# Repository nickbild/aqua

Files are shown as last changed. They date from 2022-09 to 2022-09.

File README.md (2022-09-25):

# Aqua

Aqua turns the underpowered Mattel Aquarius into a respectable computer by adding 32 KB of RAM and SD card mass storage.

The Mattel Aquarius home computer was released in June of 1983 and had already been discontinued by October of that same year.  The short lifespan of this machine is no big surprise — it is equipped with 4 KB of RAM, which is reduced to 1.7 KB of free RAM after factoring in the reserved video memory and system variables.  It also has a terrible rubber chiclet keyboard that is not quite large enough for adult hands.  But despite these (and many more!) flaws, beyond all reason, I still love this computer so I wanted to give mine a little help.  By adding 32 KB of additional memory it is much more usable, and the SD card reader allows me to write software on a modern machine, then easily load it onto the Aquarius, which means I don't have to try to type in long programs on its awful keyboard (or use the cassette port, which is slow and fails far more than it succeeds).

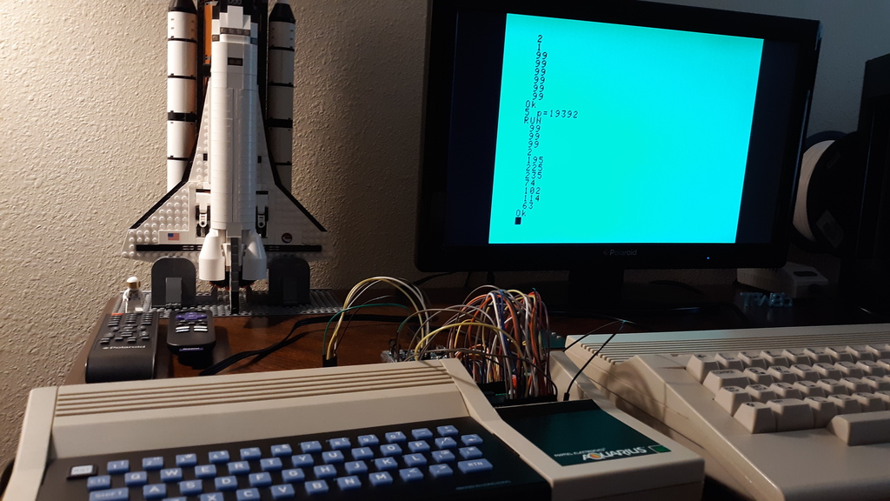
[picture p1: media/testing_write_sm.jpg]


## How It Works

The Aqua PCB ([KiCad files here](https://github.com/nickbild/aqua/tree/main/aqua_pcb)) is designed to plug into the cartridge port of the Aquarius.  It has a 32 KB SRAM chip and logic chips to map it into the 32K addresses above onboard memory ($4000-$BFFF).  It also has a pin header that gives easy access to the cartridge port's connectors.  These are quite useful since the computer offers hardly any other options for extension, and the cartridge port offers direct, unbuffered access to the address and data bus, and virtually all other signals on the Z80.

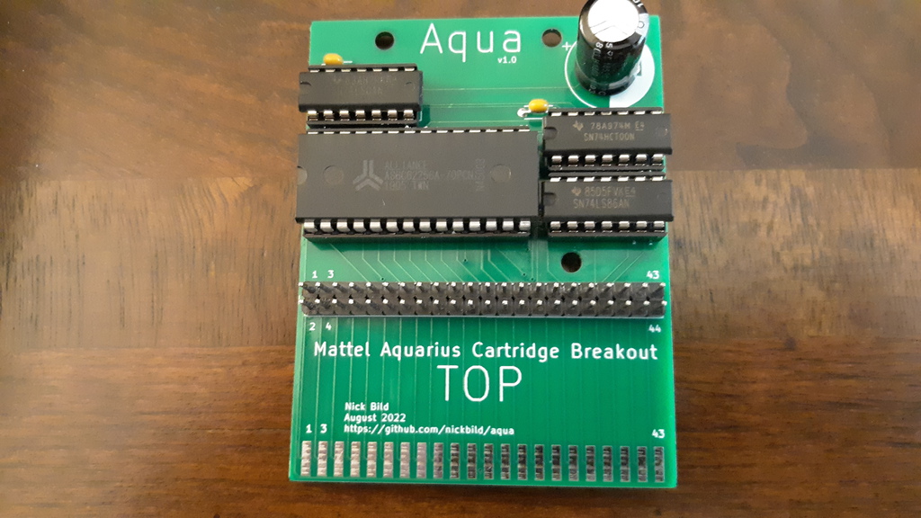
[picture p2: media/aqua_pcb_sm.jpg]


Aqua brings the Aquarius closer to being in the same league as other contemporary computers, but there is still no decent way to load programs onto it — and using the computer's keyboard to type them is a terrible experience.  So I built AquaWrite, which connects to Aqua's pin header, to load programs/data into memory on the Aquarius from an SD card.  Using AquaWrite, it is possible to write and assemble programs on a modern computer, then write the machine code, as a sequence of newline-delimited bytes, to a text file.  That card can be inserted into AquaWrite and loaded into memory in a few seconds.

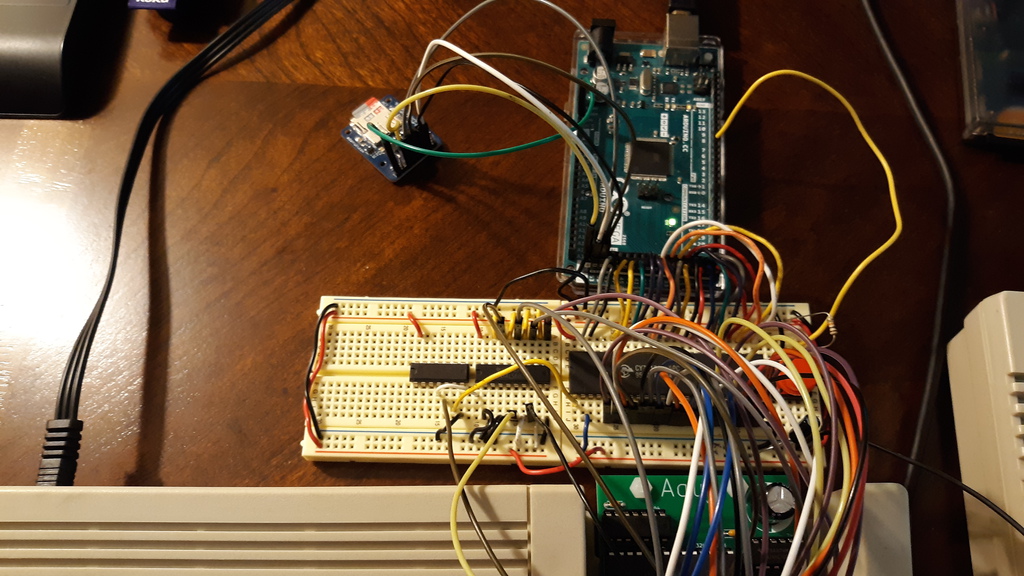
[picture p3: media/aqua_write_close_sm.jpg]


AquaWrite ([KiCad files here](https://github.com/nickbild/aqua/tree/main/aqua_write_pcb)) uses an Arduino Mega 2560 ([Arduino code here](https://github.com/nickbild/aqua/tree/main/aqua_write)) to handle SD card access and writing that data to a 1 KB dual-port SRAM chip.  That SRAM chip is mapped to addresses $FC00-$FFFF, and is used to transfer programs of any size into lower memory addresses in 1 KB pages.  The Arduino first writes a small (20 byte) program in machine code to the SRAM, then the next 1,004 bytes to be transferred.  When ready, the user is prompted to run a `USR` call that executes the machine code and transfers the bytes to a lower memory address.  This method is used because the Aquarius prevents access to addresses in the range of this SRAM from BASIC.  If the data to transfer exceeds 1004 bytes, the user presses a button on AquaWrite to load up each additional segment, then again runs `USR` to move the data to the next set of memory addresses.  Any size program (up to the limits of the Aquarius' memory) can be loaded in this way.

This is a bit more complicated because the Aquarius uses an early form of copy protection for external devices (anything that is not onboard the stock computer).  A PLA sits between the Z80 and data bus that XORs data with a software lock code (initialized to a random value on startup), which would scramble any values loaded via SD.  So before using AquaWrite for the first time after start up, a sequence of commands needs to run to disable this software lock:

```
poke 14510,63
poke 14412,63
poke 14530,63

10 print 1
run

poke 15250,175
poke 15251,211
poke 15252,255
poke 15253,201

poke 14341,59
poke 14340,146
x=usr(0)

poke 14510,191
poke 14412,191
poke 14530,191

run
```

This (temporarily) relocates the stack and other system variables to onboard memory (before the lock code is changed and they get scrambled), then runs a simple program that writes a `0` to the I/O port at $FF that stores the software lock code.  Since data is encoded/decoded by XORing it with the lock code, setting that code to `0` effectively turns it off — the result is always the same as the initial value.

Aqua:


AquaWrite:


## Media

The Aqua board, which adds 32 KB of SRAM and breaks the cartridge port connectors out into a pin header for easy access:

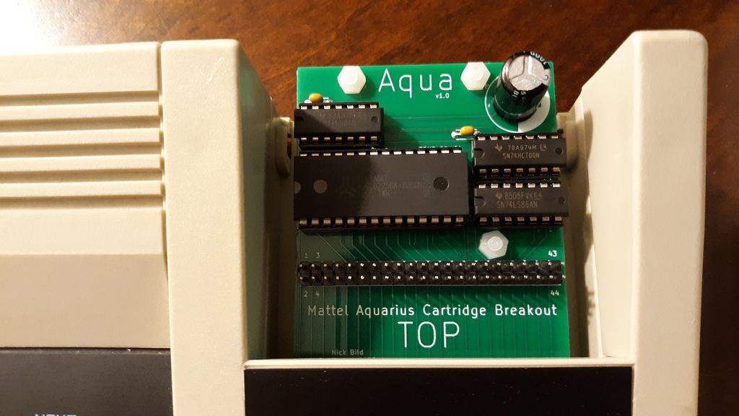
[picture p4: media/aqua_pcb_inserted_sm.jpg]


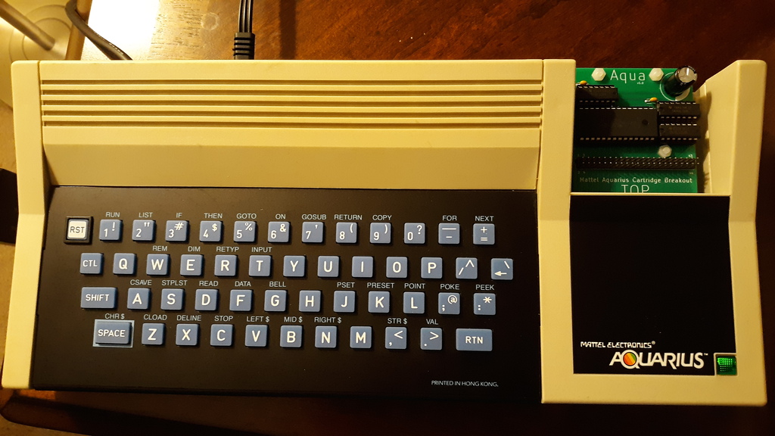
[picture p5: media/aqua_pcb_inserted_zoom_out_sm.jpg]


AquaWrite, which enables loading data from an SD card to Aquarius RAM:

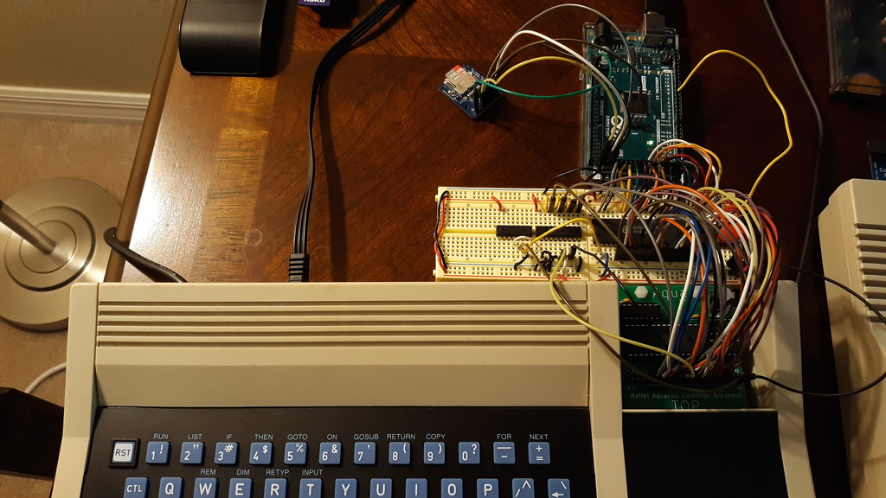
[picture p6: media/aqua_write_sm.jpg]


## Bill of Materials

Aqua:
- Aqua PCB ([KiCad files here](https://github.com/nickbild/aqua/tree/main/aqua_pcb))
- 1 x 32 KB SRAM chip
- 1 x 74LS00
- 1 x 74LS86
- 1 x 74LS04
- 4 x 0.1 uF ceramic capacitors
- 1 x 1000 uF electrolytic capacitor
- 2 x 10mm M3 standoffs
- 2 x 15mm M3 standoffs
- 44 x male pin headers

AquaWrite:
- 1 x CY7C130-55PC 1 KB dual-port SRAM
- 1 x 74LS682
- 1 x 74LS32
- 1 x Arduino Mega 2560
- 1 x SD card breakout board
- 1 x 0.1 uF ceramic capacitors
- 1 x 47 uF electrolytic capacitor
- 1 x 10K ohm resistor
- 1 x pushbutton

## About the Author

[Nick A. Bild, MS](https://nickbild79.firebaseapp.com/#!/)

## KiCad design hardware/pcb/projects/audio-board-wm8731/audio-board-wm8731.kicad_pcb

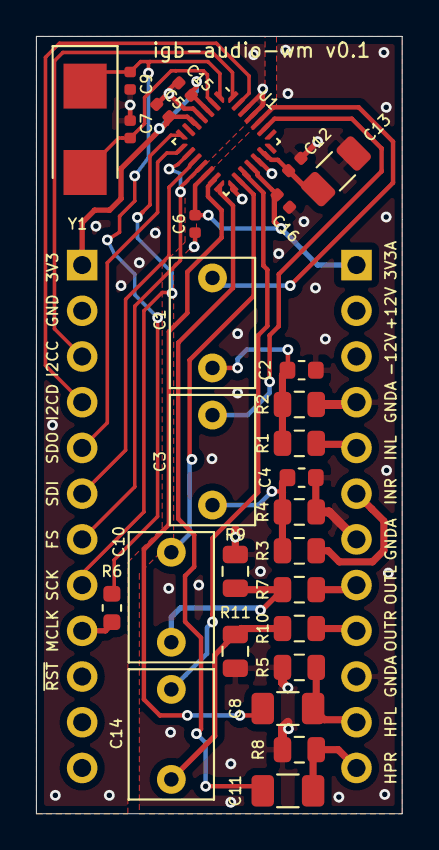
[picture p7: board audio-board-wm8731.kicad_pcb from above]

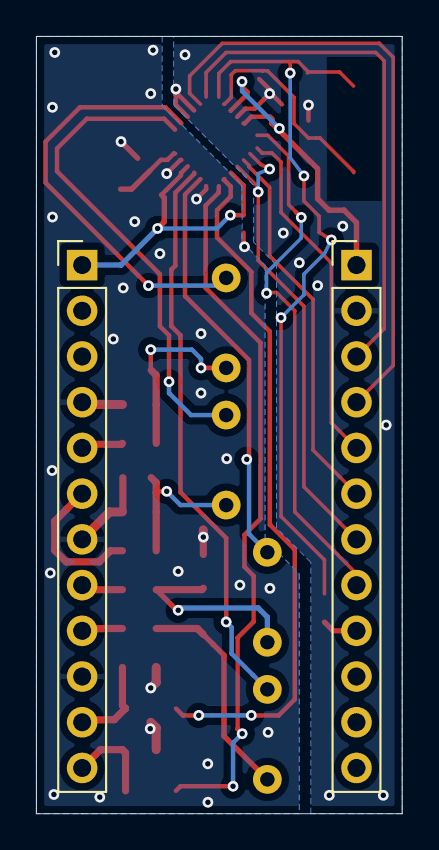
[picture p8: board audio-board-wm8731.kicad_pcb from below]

Board: 2 copper layers, 20.3 x 43.2 mm, 31 parts (2 on the bottom side), 30 nets.

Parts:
C1, C3, C10, C14: 1u; C_Rect_L7.0mm_W4.5mm_P5.00mm
C2, C4: 220p; C_0603_1608Metric
C5, C6, C12, C15, C16: 100n; C_0402_1005Metric
C7, C9: 18p; C_0402_1005Metric
C8, C11: 100u; C_1206_3216Metric
C13: 10u; C_1206_3216Metric
J1, J2: Conn_01x12; PinHeader_1x12_P2.54mm_Vertical
R1, R2, R3, R4: 10k; R_0805_2012Metric
R5, R8, R9, R11: 100k; R_0805_2012Metric
R6: 0; R_0603_1608Metric
R7, R10: 100; R_0805_2012Metric
U1: wm8731_qfn; QFN-28_4x4mm_P0.5mm
Y1: 12.288MHz; Crystal_SMD_Abracon_ABM3-2pin_5.0x3.2mm_hand

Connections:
+3.3VA: C6.2, C16.2, J1.1, U1.12, U1.18
+3V3: C5.2, C15.2, J2.1, U1.3, U1.5
/ADC_L: C1.2, U1.24
/ADC_R: C3.2, U1.23
/DAC_L: C10.2, U1.16
/DAC_R: C14.2, U1.17
/HP_OUT_L: C8.2, J1.11, R5.2
/HP_OUT_R: C11.2, J1.12, R8.2
/I2C_SCL: J2.3, U1.28
/I2C_SDA: J2.4, U1.27
/I2S_FS: J2.7, U1.9, U1.11
/I2S_MCLK: J2.9, R6.1
/I2S_SCK: J2.8, U1.7
/I2S_SDI: J2.6, U1.10
/I2S_SDO: J2.5, U1.8
/LINE_IN_L: J1.5, R1.2
/LINE_IN_R: J1.6, R3.2
/LINE_OUT_L: J1.8, R7.2
/LINE_OUT_R: J1.9, R10.2
GND: C5.1, C7.2, C9.2, C15.1, J2.2, U1.4, U1.25, U1.26
GNDA: C2.1, C4.1, C6.1, C12.2, C13.2, C16.1, J1.4, J1.7, J1.10, R2.2, R4.2, R5.1, R8.1, R9.1, R11.1, U1.15, U1.19
unnamed: C1.1, C2.2, R1.1, R2.1
unnamed: C3.1, C4.2, R3.1, R4.1
unnamed: C7.1, U1.2, Y1.2
unnamed: C8.1, U1.13
unnamed: C9.1, R6.2, U1.1, Y1.1
unnamed: C10.1, R7.1, R9.2
unnamed: C11.1, U1.14
unnamed: C12.1, C13.1, U1.20
unnamed: C14.1, R10.1, R11.2

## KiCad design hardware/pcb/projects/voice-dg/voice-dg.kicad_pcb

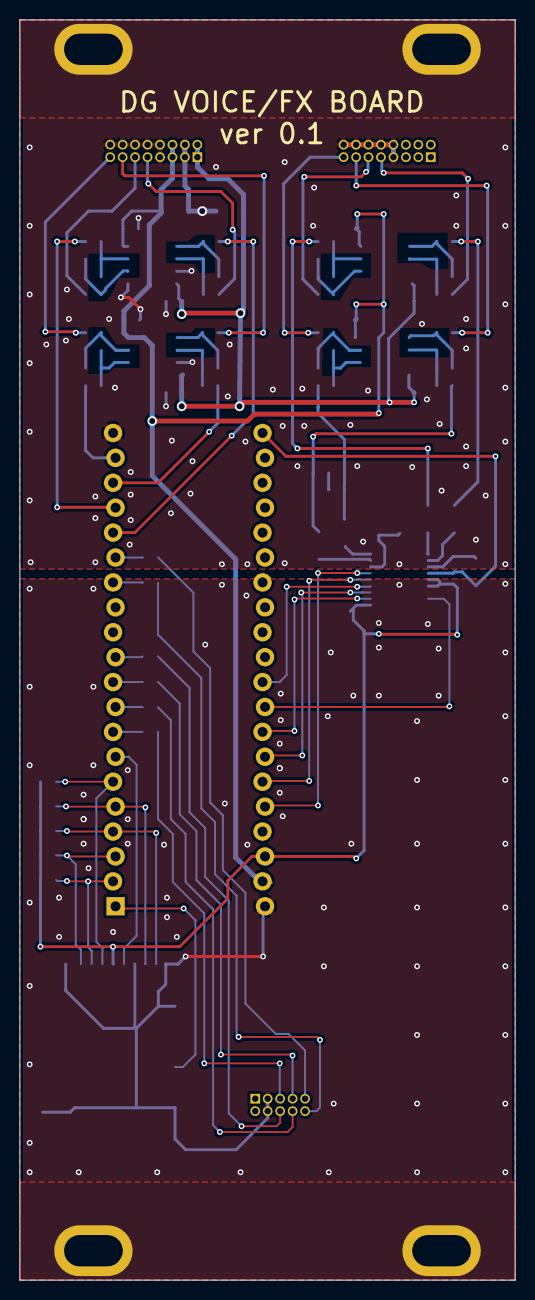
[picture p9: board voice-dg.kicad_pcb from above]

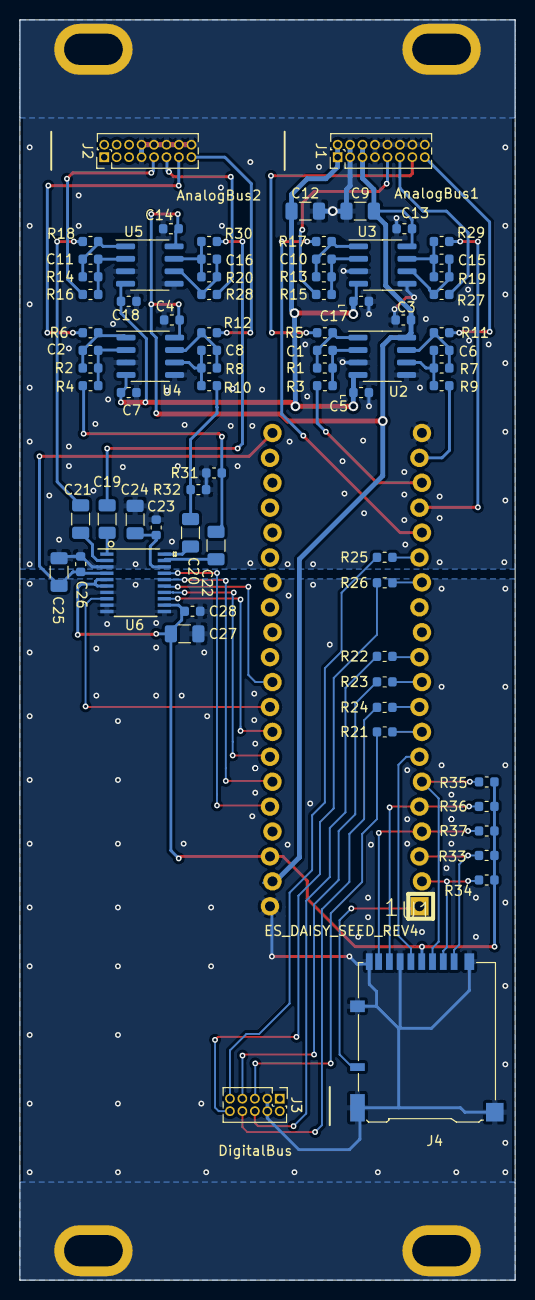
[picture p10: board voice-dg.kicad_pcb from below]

Board: 2 copper layers, 50.5 x 128.5 mm, 75 parts (75 on the bottom side), 68 nets.

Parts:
C1, C2, C6, C8, C10, C11, C15, C16: 12p; C_0603_1608Metric
C3, C4, C5, C7, C13, C14, C17, C18, C23, C26, C28: 100n; C_0603_1608Metric
C9, C12: 22u; C_1206_3216Metric
C19, C20, C21, C22, C25, C27: 10u; C_1206_3216Metric
C24: 2.2u; C_1206_3216Metric
J1: AnalogBus; PinHeader_2x08_P1.27mm_Vertical
J2: AnalogBusEx; PinHeader_2x08_P1.27mm_Vertical
J3: DigitalBus; PinHeader_2x05_P1.27mm_Vertical
J4: Micro_SD_Card_Det_Hirose_DM3AT; microSD_HC_Hirose_DM3AT-SF-PEJM5_hand
R1, R2, R7, R8, R15, R16, R27, R28: 100k; R_0603_1608Metric
R3, R4, R9, R10, R13, R14, R19, R20: 10k; R_0603_1608Metric
R5, R6, R11, R12, R17, R18, R29, R30: 470; R_0603_1608Metric
R21, R22, R23, R24, R25, R26: 47; R_0603_1608Metric
R31, R32, R33, R34, R35, R36, R37: 47k; R_0603_1608Metric
U1: ES_DAISY_SEED_REV4; ES_DAISY_SEED
U2, U3, U4, U5: OPA2134; SOIC-8_3.9x4.9mm_P1.27mm
U6: AK4556VT

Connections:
+3.3VA: C25.2, C26.1, U1.21, U6.4
+3V3: C27.2, C28.1, J4.4, R33.2, R34.2, R35.2, R36.2, R37.2, U1.38, U6.5, U6.6, U6.12
+12V: C3.1, C4.1, C9.2, C13.1, C14.1, J1.5, J1.6, U1.39, U2.8, U3.8, U4.8, U5.8
-12V: C5.1, C7.1, C12.1, C17.1, C18.1, J1.1, J1.2, U2.4, U3.4, U4.4, U5.4
/AK4556_RST: U1.36, U6.17
/AnalogIn1: J1.9, R15.2
/AnalogIn2: J1.11, R27.2
/AnalogIn3: J2.9, R16.2
/AnalogIn4: J2.11, R28.2
/AnalogOut1: J1.13, R5.1
/AnalogOut2: J1.15, R11.1
/AnalogOut3: J2.13, R6.1
/AnalogOut4: J2.15, R12.1
/DG_AUDIO_IN_L: R17.1, U1.16
/DG_AUDIO_IN_R: R29.1, U1.17
/DG_AUDIO_OUT_L: R3.2, U1.18
/DG_AUDIO_OUT_R: R9.2, U1.19
/EX_AUDIO_IN_L: C21.1, R18.1
/EX_AUDIO_IN_R: C19.1, R30.1
/EX_AUDIO_OUT_L: C22.2, R4.2, R31.2
/EX_AUDIO_OUT_R: C20.2, R10.2, R32.2
/SAI2_FS_B: U1.34, U6.14
/SAI2_MCLK_B: U1.31, U6.15
/SAI2_SCK_B: U1.35, U6.16
/SAI2_SD_A: U1.33, U6.13
/SAI2_SD_B: U1.32, U6.8
/SD_CLK: J4.5, U1.7
/SD_CMD: J4.3, R35.1, U1.6
/SD_D0: J4.7, R36.1, U1.5
/SD_D1: J4.8, R37.1, U1.4
/SD_D2: J4.1, R33.1, U1.3
/SD_D3: J4.2, R34.1, U1.2
/SPI_MISO: R23.2, U1.10
/SPI_MOSI: R22.1, U1.11
/SPI_SCK: R24.1, U1.9
/USART_RX: R25.2, U1.15
/USART_TX: R26.1, U1.14
/~SD_SW: J4.10, U1.1
/~SPI_CS: R21.2, U1.8
GND: C27.1, C28.2, J3.3, J3.4, J4.6, J4.9, J4.11, U1.40, U6.7, U6.9, U6.10, U6.11
GNDA: C3.2, C4.2, C5.2, C7.2, C9.1, C12.2, C13.2, C14.2, C17.2, C18.2, C23.2, C24.1, C25.1, C26.2, J1.3, J1.4, J1.7, J1.8, J1.10, J1.12, J1.14, J1.16, J2.7, J2.8, J2.10, J2.12, J2.14, J2.16, R31.1, R32.1, U1.20, U2.3, U2.5, U3.3, U3.5, U4.3, U4.5, U5.3, U5.5, U6.3
unnamed: C1.1, R1.1, R5.2, U2.1
unnamed: C1.2, R1.2, R3.1, U2.2
unnamed: C2.1, R2.1, R6.2, U4.1
unnamed: C2.2, R2.2, R4.1, U4.2
unnamed: C6.1, R7.1, R11.2, U2.7
unnamed: C6.2, R7.2, R9.1, U2.6
unnamed: C8.1, R8.1, R12.2, U4.7
unnamed: C8.2, R8.2, R10.1, U4.6
unnamed: C10.1, R13.1, R17.2, U3.1
unnamed: C10.2, R13.2, R15.1, U3.2
unnamed: C11.1, R14.1, R18.2, U5.1
unnamed: C11.2, R14.2, R16.1, U5.2
unnamed: C15.1, R19.1, R29.2, U3.7
unnamed: C15.2, R19.2, R27.1, U3.6
unnamed: C16.1, R20.1, R30.2, U5.7
unnamed: C16.2, R20.2, R28.1, U5.6
unnamed: C19.2, U6.1
unnamed: C20.1, U6.20
unnamed: C21.2, U6.2
unnamed: C22.1, U6.19
unnamed: C23.1, C24.2, U6.18
unnamed: J3.5, R21.1
unnamed: J3.6, R22.2
unnamed: J3.7, R23.1
unnamed: J3.8, R24.2
unnamed: J3.9, R25.1
unnamed: J3.10, R26.2

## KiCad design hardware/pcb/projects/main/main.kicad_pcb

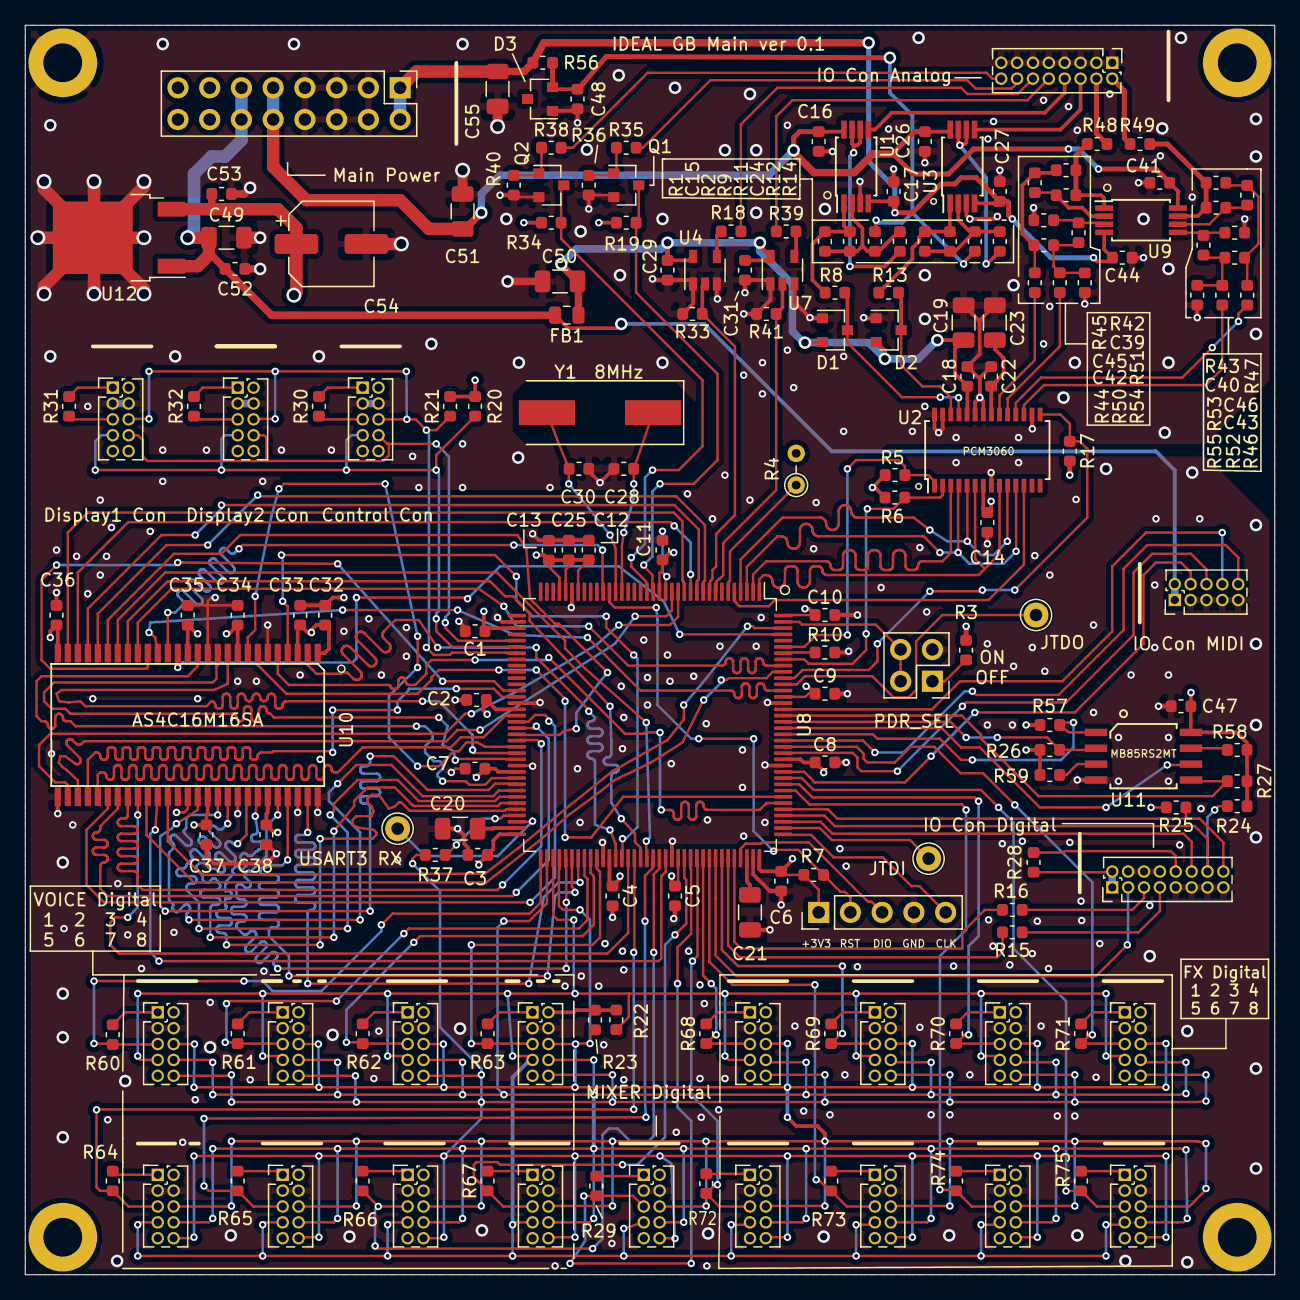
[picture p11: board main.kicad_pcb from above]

Board: 4 copper layers, 100.0 x 100.0 mm, 176 parts (0 on the bottom side), 154 nets.

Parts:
C1, C2, C3, C4, C5, C6, C7, C8, C9, C10, C11, C12, C13, C14, C16, C17, C18, C22, C25, C26, C27, C29, C31, C32, C33, C34, C35, C36, C37, C38, C41, C44, C47, C48, C52, C53: 100n; C_0603_1608Metric
C15, C24, C28, C30: 18p; C_0603_1608Metric
C19, C23: 10u; C_1206_3216Metric
C20, C21: 2.2u; C_1206_3216Metric
C39, C40, C45, C46: 470p; C_0603_1608Metric
C42, C43: 2.2n; C_0603_1608Metric
C49, C50, C51, C55: 22u; C_1206_3216Metric
C54: 100u; CP_Elec_6.3x5.3
D1, D2: BAT54S; SOT-23
D3: LM4040; SOT-23
FB1: Ferrite; R_0805_2012Metric
J1: IO_CON_ANALOG; PinHeader_2x08_P1.27mm_Vertical
J2: PDR_ON_SEL; PinHeader_2x02_P2.54mm_Vertical
J3: VOICE1_DIGITAL; PinHeader_2x05_P1.27mm_Vertical
J4: FX1_DIGITAL; PinHeader_2x05_P1.27mm_Vertical
J5: VOICE5_DIGITAL; PinHeader_2x05_P1.27mm_Vertical
J6: FX5_DIGITAL; PinHeader_2x05_P1.27mm_Vertical
J7: VOICE2_DIGITAL; PinHeader_2x05_P1.27mm_Vertical
J8: FX2_DIGITAL; PinHeader_2x05_P1.27mm_Vertical
J9: VOICE6_DIGITAL; PinHeader_2x05_P1.27mm_Vertical
J10: FX6_DIGITAL; PinHeader_2x05_P1.27mm_Vertical
J11: VOICE3_DIGITAL; PinHeader_2x05_P1.27mm_Vertical
J12: FX3_DIGITAL; PinHeader_2x05_P1.27mm_Vertical
J13: VOICE7_DIGITAL; PinHeader_2x05_P1.27mm_Vertical
J14: FX7_DIGITAL; PinHeader_2x05_P1.27mm_Vertical
J15: IO_CON_MIDI; PinHeader_2x05_P1.27mm_Vertical
J16: VOICE4_DIGITAL; PinHeader_2x05_P1.27mm_Vertical
J17: FX4_DIGITAL; PinHeader_2x05_P1.27mm_Vertical
J18: VOICE8_DIGITAL; PinHeader_2x05_P1.27mm_Vertical
J19: FX8_DIGITAL; PinHeader_2x05_P1.27mm_Vertical
J20: SWD_CON; PinHeader_1x05_P2.54mm_Vertical
J21: MIXER_DIGITAL; PinHeader_2x05_P1.27mm_Vertical
J22: DISPLAY1_DIGITAL; PinHeader_2x05_P1.27mm_Vertical
J23: IO_CON_DIGITAL; PinHeader_2x08_P1.27mm_Vertical
J24: POWER_CON; PinHeader_2x08_P2.54mm_Vertical
J25: CONTROL_DIGTAL; PinHeader_2x05_P1.27mm_Vertical
J26: DISPLAY2_DIGITAL; PinHeader_2x05_P1.27mm_Vertical
Q1, Q2: MMBT3904; SOT-23
R1, R11: 30k; R_0603_1608Metric
R2, R12: 120k; R_0603_1608Metric
R3, R5, R6, R7, R10, R17, R19, R20, R21, R22, R23, R24, R25, R26, R27, R28, R29, R30, R31, R32, R33, R34, R41, R57, R58, R59, R60, R61, R62, R63, R64, R65, R66, R67, R68, R69, R70, R71, R72, R73, R74, R75: 10k; R_0603_1608Metric
R4: 0; R_Axial_DIN0204_L3.6mm_D1.6mm_P2.54mm_Vertical
R8, R13, R48, R49: 470; R_0603_1608Metric
R9, R14: 200k; R_0603_1608Metric
R15, R16, R37: 10; R_0603_1608Metric
R18, R39, R45, R47, R51, R53: 1k; R_0603_1608Metric
R35, R36, R38, R40: 100k; R_0603_1608Metric
R42, R43, R54, R55: 12k; R_0603_1608Metric
R44, R46, R50, R52: 4.7k; R_0603_1608Metric
R56: 3.3k; R_0603_1608Metric
TP1: JTDI; Pin_D1.0mm_L10.0mm
TP2: JTDO; Pin_D1.0mm_L10.0mm
TP3: USART3_RX; Pin_D1.0mm_L10.0mm
U1, U3, U9: TL072; TSSOP-8_4.4x3mm_P0.65mm
U2: PCM3060; TSSOP-28_4.4x9.7mm_P0.65mm
U4, U7: 74AHCT1G125; SOT-23-5
U8: STM32F446ZETx; LQFP-144_20x20mm_P0.5mm
U10: AS4C16M16SA
U11: MB85RS2MT
U12: L7803; TO-252-2
Y1: 8MHz; Crystal_SMD_HC49-SD

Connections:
+3V3: C1.1, C2.1, C3.1, C4.1, C5.1, C6.1, C7.1, C8.1, C9.1, C10.1, C11.1, C12.1, C13.1, C14.1, C25.1, C32.1, C33.1, C34.1, C35.1, C36.1, C37.1, C38.1, C47.2, C53.1, C54.1, J3.1, J3.2, J4.1, J4.2, J5.1, J5.2, J6.1, J6.2, J7.1, J7.2, J8.1, J8.2, J9.1, J9.2, J10.1, J10.2, J11.1, J11.2, J12.1, J12.2, J13.1, J13.2, J14.1, J14.2, J16.1, J16.2, J17.1, J17.2, J18.1, J18.2, J19.1, J19.2, J20.1, J21.1, J21.2, J22.1, J22.2, J23.1, J23.2, J25.1, J25.2, J26.1, J26.2, R3.2, R4.2, R5.2, R6.2, R7.2, R17.2, R19.1, R20.2, R21.2, R22.2, R23.2, R24.2, R25.2, R26.2, R27.2, R28.2, R29.2, R30.2, R31.2, R32.2, R34.1, R57.2, R58.2, R59.2, R60.2, R61.2, R62.2, R63.2, R64.2, R65.2, R66.2, R67.2, R68.2, R69.2, R70.2, R71.2, R72.2, R73.2, R74.2, R75.2, U2.7, U8.17, U8.30, U8.32, U8.33, U8.39, U8.52, U8.62, U8.72, U8.84, U8.95, U8.108, U8.121, U8.131, U8.144, U10.1, U10.3, U10.9, U10.14, U10.27, U10.43, U10.49, U11.8, U12.3
+5V: C49.1, C52.1, FB1.2, J15.1, J15.2, J24.11, J24.12, U12.1
+5VA: C18.1, C19.1, C29.1, C31.1, C50.1, D1.2, D2.2, FB1.1, U2.24, U4.5, U7.5
+12V: C16.1, C26.1, C41.1, C51.1, J24.9, J24.10, U1.8, U3.8, U9.8
-12V: C17.2, C27.2, C44.2, C55.2, J24.1, J24.2, R56.2, U1.4, U3.4, U9.4
/FMC_A0: U8.10, U10.23
/FMC_A1: U8.11, U10.24
/FMC_A2: U8.12, U10.25
/FMC_A3: U8.13, U10.26
/FMC_A4: U8.14, U10.29
/FMC_A5: U8.15, U10.30
/FMC_A6: U8.50, U10.31
/FMC_A7: U8.53, U10.32
/FMC_A8: U8.54, U10.33
/FMC_A9: U8.55, U10.34
/FMC_A10: U8.56, U10.22
/FMC_A11: U8.57, U10.35
/FMC_A12: U8.87, U10.36
/FMC_BA0: U8.89, U10.20
/FMC_BA1: U8.90, U10.21
/FMC_D0: U8.85, U10.2
/FMC_D1: U8.86, U10.4
/FMC_D2: U8.114, U10.5
/FMC_D3: U8.115, U10.7
/FMC_D4: U8.58, U10.8
/FMC_D5: U8.59, U10.10
/FMC_D6: U8.60, U10.11
/FMC_D7: U8.63, U10.13
/FMC_D8: U8.64, U10.42
/FMC_D9: U8.65, U10.44
/FMC_D10: U8.66, U10.45
/FMC_D11: U8.67, U10.47
/FMC_D12: U8.68, U10.48
/FMC_D13: U8.77, U10.50
/FMC_D14: U8.78, U10.51
/FMC_D15: U8.79, U10.53
/FMC_NBL0: U8.141, U10.15
/FMC_NBL1: U8.142, U10.39
/FMC_SDCKE1: U8.135, U10.37
/FMC_SDCLK: U8.93, U10.38
/FMC_SDNCAS: U8.132, U10.17
/FMC_SDNE1: U8.136, U10.19
/FMC_SDNRAS: U8.49, U10.18
/FMC_SDNWE: U8.26, U10.16
/I2C_SCL: R5.1, U2.1, U8.139
/I2C_SDA: R6.1, U2.2, U8.137
/OTG_FS_DM: J23.7, R15.1
/OTG_FS_DP: J23.5, R16.1
/OTG_FS_VBUS: J23.3, U8.101
/SAI1_FS_A: U2.4, U2.11, U8.3
/SAI1_MCLK_A: U2.6, U2.9, U8.1
/SAI1_SCK_A: U2.5, U2.10, U8.4
/SAI1_SD_A: U2.12, U8.5
/SAI1_SD_B: U2.3, U8.2
/SPI1_MISO: J22.7, J25.7, J26.7, R20.1, U8.42
/SPI1_MOSI: J22.6, J25.6, J26.6, R21.1, U8.43
/SPI1_SCK: J22.8, J25.8, J26.8, U8.41
/SPI2_MISO: J3.7, J4.7, J5.7, J6.7, J7.7, J8.7, J9.7, J10.7, J11.7, J12.7, J13.7, J14.7, J16.7, J17.7, J18.7, J19.7, J21.7, R22.1, U8.75
/SPI2_MOSI: J3.6, J4.6, J5.6, J6.6, J7.6, J8.6, J9.6, J10.6, J11.6, J12.6, J13.6, J14.6, J16.6, J17.6, J18.6, J19.6, J21.6, R23.1, U8.76
/SPI2_SCK: J3.8, J4.8, J5.8, J6.8, J7.8, J8.8, J9.8, J10.8, J11.8, J12.8, J13.8, J14.8, J16.8, J17.8, J18.8, J19.8, J21.8, U8.74
/SPI3_MISO: J23.14, R24.1, U8.112
/SPI3_MOSI: J23.16, R25.1, U8.113
/SPI3_SCK: J23.12, U8.111
/SPI4_MISO: R26.1, U8.127, U11.2
/SPI4_MOSI: R27.1, U8.128, U11.5
/SPI4_SCK: U8.126, U11.6
/SWCLK: J20.5, U8.109
/SWDIO: J20.3, U8.105
/USART2_RX: J15.6, U8.122
/USART2_TX: J15.4, U8.119
/USART3_TX: J3.10, J4.10, J5.10, J6.10, J7.10, J8.10, J9.10, J10.10, J11.10, J12.10, J13.10, J14.10, J16.10, J17.10, J18.10, J19.10, J21.10, R37.1
/USART6_RX: J15.10, U8.124
/USART6_TX: J15.8, U8.129
/~CONTROL_SPI_CS: J25.5, R30.1
/~DAC_RESET: R17.1, U2.15, U8.134
/~DISPLAY1_SPI_CS: J22.5, R31.1
/~DISPLAY2_SPI_CS: J26.5, R32.1
/~FRAM_SPI_CS: R57.1, U8.125, U11.1
/~FX1_SPI_CS: J4.5, R68.1, U8.99
/~FX2_SPI_CS: J8.5, R69.1, U8.102
/~FX3_SPI_CS: J12.5, R70.1, U8.117
/~FX4_SPI_CS: J17.5, R71.1, U8.123
/~FX5_SPI_CS: J6.5, R72.1, U8.98
/~FX6_SPI_CS: J10.5, R73.1, U8.100
/~FX7_SPI_CS: J14.5, R74.1, U8.116
/~FX8_SPI_CS: J19.5, R75.1, U8.118
/~MIXER_SPI_CS: J21.5, R29.1, U8.97
/~RESET: J20.2, R7.1, U8.25
/~SD_SPI_CS: J23.10, R28.1
/~VOICE1_SPI_CS: J3.5, R60.1, U8.73
/~VOICE2_SPI_CS: J7.5, R61.1, U8.80
/~VOICE3_SPI_CS: J11.5, R62.1, U8.81
/~VOICE4_SPI_CS: J16.5, R63.1, U8.82
/~VOICE5_SPI_CS: J5.5, R64.1, U8.88
/~VOICE6_SPI_CS: J9.5, R65.1, U8.91
/~VOICE7_SPI_CS: J13.5, R66.1, U8.92
/~VOICE8_SPI_CS: J18.5, R67.1, U8.96
CV1_IN: J1.8, U1.5
CV1_OUT: J1.4, R48.2
CV2_IN: J1.6, U3.5
CV2_OUT: J1.2, R49.2
DAC_IN_L: D1.3, R8.1, U2.25
DAC_IN_R: D2.3, R13.1, U2.26
DAC_VOUTL+: R44.1, U2.20
DAC_VOUTL-: R50.1, U2.19
DAC_VOUTR+: R46.1, U2.18
DAC_VOUTR-: R52.1, U2.17
GATE1_IN: J1.16, R38.2
GATE1_IN_BUF_OUT: Q2.3, R34.2, U8.19
GATE1_OUT: J1.12, R18.1
GATE1_OUT_BUF_IN: R33.1, U4.2, U8.9
GATE2_IN: J1.14, R35.2
GATE2_IN_BUF_OUT: Q1.3, R19.2, U8.18
GATE2_OUT: J1.10, R39.1
GATE2_OUT_BUF_IN: R41.1, U7.2, U8.8
GND: C1.2, C2.2, C3.2, C4.2, C5.2, C6.2, C7.2, C8.2, C9.2, C10.2, C11.2, C12.2, C13.2, C14.2, C16.2, C17.1, C18.2, C19.2, C20.2, C21.2, C22.1, C23.1, C25.2, C26.2, C27.1, C28.2, C29.2, C30.2, C31.2, C32.2, C33.2, C34.2, C35.2, C36.2, C37.2, C38.2, C41.2, C44.1, C45.1, C46.1, C47.1, C48.2, C49.2, C50.2, C51.2, C52.2, C53.2, C54.2, C55.1, D1.1, D2.1, D3.1, J1.1, J1.3, J1.5, J1.7, J1.9, J1.11, J1.13, J1.15, J2.3, J3.3, J3.4, J4.3, J4.4, J5.3, J5.4, J6.3, J6.4, J7.3, J7.4, J8.3, J8.4, J9.3, J9.4, J10.3, J10.4, J11.3, J11.4, J12.3, J12.4, J13.3, J13.4, J14.3, J14.4, J15.3, J15.5, J15.7, J15.9, J16.3, J16.4, J17.3, J17.4, J18.3, J18.4, J19.3, J19.4, J20.4, J21.3, J21.4, J22.3, J22.4, J23.4, J23.6, J23.8, J23.9, J23.11, J23.13, J23.15, J24.3, J24.4, J24.5, J24.6, J24.7, J24.8, J25.3, J25.4, J26.3, J26.4, Q1.2, Q2.2, R10.2, R33.2, R36.2, R40.2, R41.2, R54.1, R55.1, U1.3, U2.8, U2.16, U2.22, U2.23, U2.27, U2.28, U3.3, U4.1, U4.3, U7.1, U7.3, U8.16, U8.31, U8.38, U8.51, U8.61, U8.83, U8.94, U8.107, U8.120, U8.130, U10.6, U10.12, U10.28, U10.41, U10.46, U10.52, U10.54, U11.4, U12.2
unnamed: C15.1, R1.2, R2.1, R9.1, U1.2
unnamed: C15.2, R1.1, R8.2, U1.1
unnamed: C20.1, U8.71
unnamed: C21.1, U8.106
unnamed: C22.2, C23.2, U2.21
unnamed: C24.1, R11.2, R12.1, R14.1, U3.2
unnamed: C24.2, R11.1, R13.2, U3.1
unnamed: C28.1, U8.23, Y1.1
unnamed: C30.1, U8.24, Y1.2
unnamed: C39.1, R45.2, U9.2
unnamed: C39.2, R42.2, R48.1, U9.1
unnamed: C40.1, R47.2, U9.6
unnamed: C40.2, R43.2, R49.1, U9.7
unnamed: C42.1, R42.1, R44.2, R45.1
unnamed: C42.2, R50.2, R51.1, R54.2
unnamed: C43.1, R43.1, R46.2, R47.1
unnamed: C43.2, R52.2, R53.1, R55.2
unnamed: C45.2, R51.2, U9.3
unnamed: C46.2, R53.2, U9.5
unnamed: J2.1, R3.1
unnamed: J2.2, J2.4, U8.143
unnamed: Q1.1, R35.1, R36.1
unnamed: Q2.1, R38.1, R40.1
unnamed: R4.1, U8.6
unnamed: R9.2, U1.6, U1.7
unnamed: R10.1, U8.138
unnamed: R14.2, U3.6, U3.7
unnamed: R15.2, U8.103
unnamed: R16.2, U8.104
unnamed: R18.2, U4.4
unnamed: R37.2, U8.69
unnamed: R39.2, U7.4
unnamed: R58.1, U11.7
unnamed: R59.1, U11.3
unnamed: TP1.1, U8.110
unnamed: TP2.1, U8.133
unnamed: TP3.1, U8.70
VREF_-10V: C48.1, D3.2, R2.2, R12.2, R56.1

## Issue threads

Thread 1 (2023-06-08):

Simpler circuit and 32/48 KB option modification.

zxMarce, 2023-06-08:
Hi Nick!

Recently acquired an Aquarius and started combing the web looking for expansions and cool gadgets for it.

While I have no doubt your design does work, I came with what I think maybe both a simplification and enhancement once I laid on paper and worked out the logic states in your schematic.

Instead of using three chips for decoding, I'd use a single [74LS138](https://www.ti.com/lit/ds/symlink/sn74ls138.pdf) wired as follows:

- Inputs A and B (pins 1, 2) connect to A14, A15 respectively.
- Input C (pin 3) to GND.
- Input -G2a (pin 4) and -G2b (pin 5) to -MREQ.
- Input G1 (pin 6) to +5V.
- Output Y1 (pin 14) to the cathode (negative) of an 1N4148.
- Output Y2 (pin 13) to the cathode (negative) of an 1N4148.
- The anodes of the 1N4148 are connected together and go to -CS on the RAM, with a 4.7K pullup.

The above should work as your current diagram. Half a 74LS139 may also be used, but I have more '138s than '139s, hehehe.
But wait! There's more! With just another 1N4148, a jumper, and a 64KB instead of the 32KB SRAM you can get a fully selectable 32/48KB expansion:

- Output Y3 (pin 12) to the cathode (negative) of a third 1N4148.
- Anode of this third 1N4148, to a two-pin jumper pin
- The other pin of the two-pin jumper to the other anodes, pullup and -CS on the RAM.

An ASCII schematic:

```
                   +5V
                    |
                    <
               4.7K >
                    <
    --+  1N4148     |
    14|----|<|------+----> to RAM -CS pin
      |             |
    13|----|<|------+
      |             |
    12|----|<|--o o-+
    --+         J1     <-- J1 open for 32K, closed for 48K.
LS138
```

As wired, the 74LS138 will enable (make low) output Y0 in the 0x0000-0x3FFF memory range (never should be used), output Y1 in the 0x4000-0x7FFF range, output Y2 in the 0x8000-0xBFFF range, and output Y3 in the 0xC000-0xFFFF (each output corresponding to a 16K "slot").
The diodes and pullup resistor form a '_cheapo OR-gate_', thus when any of Y1, Y2 (or Y3) are active (low), the corresponding diode is forward-biased and drives the output low, enabling the RAM.

Disclaimer: Please note that I do not know if the upper 16KB is actually usable by the Aquarius, as I have z-e-r-o experience with it so far, but I do know it has some kind of "hardware encryption" for cartridge ROMs in this area. Anyway, I read somewhere that this encryption works both ways (read/write), so for RAM it should be "transparent".

Further, the board can use two RAM footprints (one for 32K and another for 64K devices), the jumper between the anode of the third diode (the one connected to Y3) and the pullup resistor in order to have one board fit both RAM sizes.

Regards,
zxMarce.

nickbild, 2023-06-18:
There are lots of ways to accomplish this same goal, so by all means use the parts you have on hand (that's what I did!).

Thanks for sharing.  Maybe that will help someone else in the future.

Closed 2023-06-18.

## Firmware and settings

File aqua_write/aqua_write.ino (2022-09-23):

#include <SD.h>

////
// Arduino side of RAM.
////

#define CE_0 49
#define WE_0 47
#define OE_0 45

#define AD0_0 43
#define AD1_0 41
#define AD2_0 39
#define AD3_0 37
#define AD4_0 35
#define AD5_0 33
#define AD6_0 31
#define AD7_0 29
#define AD8_0 27
#define AD9_0 25

#define DATA0_0 34
#define DATA1_0 32
#define DATA2_0 30
#define DATA3_0 28
#define DATA4_0 26
#define DATA5_0 24
#define DATA6_0 22
#define DATA7_0 23

#define BUTTON 7

File myFile;
int idx = 0;
char stringArray[10];
int addr = 0;

void setup() {
  pinMode(CE_0, OUTPUT);
  pinMode(WE_0, OUTPUT);
  pinMode(OE_0, OUTPUT);

  digitalWrite(CE_0, HIGH);
  digitalWrite(WE_0, HIGH);
  digitalWrite(OE_0, HIGH);

  pinMode(AD0_0, OUTPUT);
  pinMode(AD1_0, OUTPUT);
  pinMode(AD2_0, OUTPUT);
  pinMode(AD3_0, OUTPUT);
  pinMode(AD4_0, OUTPUT);
  pinMode(AD5_0, OUTPUT);
  pinMode(AD6_0, OUTPUT);
  pinMode(AD7_0, OUTPUT);
  pinMode(AD8_0, OUTPUT);
  pinMode(AD9_0, OUTPUT);

  pinMode(DATA0_0, OUTPUT);
  pinMode(DATA1_0, OUTPUT);
  pinMode(DATA2_0, OUTPUT);
  pinMode(DATA3_0, OUTPUT);
  pinMode(DATA4_0, OUTPUT);
  pinMode(DATA5_0, OUTPUT);
  pinMode(DATA6_0, OUTPUT);
  pinMode(DATA7_0, OUTPUT);

  pinMode(BUTTON, INPUT);
    
  Serial.begin(9600);

  printSwLockDisableInstructions();
}

void loop() {  
  if (digitalRead(BUTTON) == LOW) {
    
    int next;
    int pageNum = 0;
    
    addr = 0;
    writeLoader(pageNum);

    if (!SD.begin(53)) {
      while (true);
    }
    
    myFile = SD.open("data.txt");
  
    if (myFile) {
      while ((next = myFile.read()) != -1) {
          char nextChar = (char) next;
          
          if (nextChar == '\n') {
              stringArray[idx] = '\0';
  
              // One complete line of the data file is ready at this point.
              writeByteToRam(atoi(stringArray));
              readByteFromRam();
              addr += 1;
              
              idx = 0;

              // One page complete.
              if (addr == 1024) {
                Serial.println("Page loaded. Transfer to RAM, then press button to continue.");
                printRamTransferInstructions();
                while (digitalRead(BUTTON) == HIGH) {}
                
                Serial.println("Continuing data load...");
                addr = 0;
                pageNum++;
                writeLoader(pageNum);
              }
              
          } else {
              stringArray[idx] = nextChar;
              idx += 1;
          }
      }
  
      myFile.close();
    }

    Serial.println("All SD data loaded. Transfer it to RAM.");
    printRamTransferInstructions();

    delay(2000); // Prevent button bounce.
  }
}

void writeByteToRam(int data) {
  // Set address and data.
  digitalWrite(AD0_0, bitRead(addr, 0));
  digitalWrite(AD1_0, bitRead(addr, 1));
  digitalWrite(AD2_0, bitRead(addr, 2));
  digitalWrite(AD3_0, bitRead(addr, 3));
  digitalWrite(AD4_0, bitRead(addr, 4));
  digitalWrite(AD5_0, bitRead(addr, 5));
  digitalWrite(AD6_0, bitRead(addr, 6));
  digitalWrite(AD7_0, bitRead(addr, 7));
  digitalWrite(AD8_0, bitRead(addr, 8));
  digitalWrite(AD9_0, bitRead(addr, 9));

  digitalWrite(DATA0_0, bitRead(data, 0));
  digitalWrite(DATA1_0, bitRead(data, 1));
  digitalWrite(DATA2_0, bitRead(data, 2));
  digitalWrite(DATA3_0, bitRead(data, 3));
  digitalWrite(DATA4_0, bitRead(data, 4));
  digitalWrite(DATA5_0, bitRead(data, 5));
  digitalWrite(DATA6_0, bitRead(data, 6));
  digitalWrite(DATA7_0, bitRead(data, 7));

  delay(1);
  digitalWrite(CE_0, LOW);
  digitalWrite(WE_0, LOW);
  delay(1);
  digitalWrite(WE_0, HIGH);
  digitalWrite(CE_0, HIGH);
  delay(1);

  Serial.print("Byte written:\t");
  Serial.print(data);
  Serial.print("\tAddress:\t");
  Serial.println(addr);
}

void readByteFromRam() {
  // Set address and data.
  digitalWrite(AD0_0, bitRead(addr, 0));
  digitalWrite(AD1_0, bitRead(addr, 1));
  digitalWrite(AD2_0, bitRead(addr, 2));
  digitalWrite(AD3_0, bitRead(addr, 3));
  digitalWrite(AD4_0, bitRead(addr, 4));
  digitalWrite(AD5_0, bitRead(addr, 5));
  digitalWrite(AD6_0, bitRead(addr, 6));
  digitalWrite(AD7_0, bitRead(addr, 7));
  digitalWrite(AD8_0, bitRead(addr, 8));
  digitalWrite(AD9_0, bitRead(addr, 9));

  pinMode(DATA0_0, INPUT);
  pinMode(DATA1_0, INPUT);
  pinMode(DATA2_0, INPUT);
  pinMode(DATA3_0, INPUT);
  pinMode(DATA4_0, INPUT);
  pinMode(DATA5_0, INPUT);
  pinMode(DATA6_0, INPUT);
  pinMode(DATA7_0, INPUT);

  delay(1);
  digitalWrite(CE_0, LOW);
  digitalWrite(OE_0, LOW);
  delay(1);

  String temp = String(digitalRead(DATA7_0)) + String(digitalRead(DATA6_0)) + String(digitalRead(DATA5_0)) + String(digitalRead(DATA4_0)) + String(digitalRead(DATA3_0)) + String(digitalRead(DATA2_0)) + String(digitalRead(DATA1_0)) + String(digitalRead(DATA0_0));
  int temp_i = strtol( temp.c_str(), NULL, 2 );
  Serial.print("Byte read:\t");
  Serial.println(temp_i);
  
  digitalWrite(OE_0, HIGH);
  digitalWrite(CE_0, HIGH);
  delay(1);

  pinMode(DATA0_0, OUTPUT);
  pinMode(DATA1_0, OUTPUT);
  pinMode(DATA2_0, OUTPUT);
  pinMode(DATA3_0, OUTPUT);
  pinMode(DATA4_0, OUTPUT);
  pinMode(DATA5_0, OUTPUT);
  pinMode(DATA6_0, OUTPUT);
  pinMode(DATA7_0, OUTPUT);
}

// The loader is machine code that sits at the start of the dual-port RAM chip
// memory and is used to copy the remainder of the contents to the correct SRAM location.
// This allows multiple pages of 1004 bytes (1024 minus loader size) to be copied in to memory for larger programs.
void writeLoader(int pageNum) {
  // Z80 machine code for the loader.
  uint8_t loader [] = {33, 20, 252, 1, 0, 64, 17, 238, 3, 126, 2, 35, 3, 27, 122, 179, 194, 9, 252, 201};

  // If this isn't the first page of data to load, adjust the address we are loading to (add 1004 per additional page).
  if (pageNum > 0) {
    int startLoc = 16384 + (1004 * pageNum);
    loader[4] = startLoc % 256;         // Low byte.
    loader[5] = int(startLoc / 256);    // High byte.
  }

  for (uint8_t val : loader) {
    writeByteToRam(val);
    readByteFromRam();
    addr += 1;
  }
}

void printRamTransferInstructions() {
  Serial.println("To load data to RAM:");
  Serial.println("poke 14341,252");
  Serial.println("poke 14340,0");
  Serial.println("x=usr(0)");
}

void printSwLockDisableInstructions() {
  Serial.println("Before starting, disable the Aquarius software lock:");

  Serial.println("poke 14510,63");
  Serial.println("poke 14412,63");
  Serial.println("poke 14530,63");

  Serial.println("10 print 1");
  Serial.println("run");

  Serial.println("poke 15250,175");
  Serial.println("poke 15251,211");
  Serial.println("poke 15252,255");
  Serial.println("poke 15253,201");

  Serial.println("poke 14341,59");
  Serial.println("poke 14340,146");
  Serial.println("x=usr(0)");

  Serial.println("poke 14510,191");
  Serial.println("poke 14412,191");
  Serial.println("poke 14530,191");

  Serial.println("run");
}

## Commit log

2022-08-30 Add KiCad files.
    [breakout_board-B_Cu.gbl, breakout_board-B_Mask.gbs, breakout_board-B_Paste.gbp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]
2022-08-30 Remove old gerbers.
    [breakout_board-B_Cu.gbl, breakout_board-B_Mask.gbs, breakout_board-B_Paste.gbp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]
2022-09-12 Add gerbers.
    [breakout_board-B_Cu.gbl, breakout_board-B_Mask.gbs, breakout_board-B_Paste.gbp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]
2022-09-23 Disable the external device encryption.
2022-09-24 Add schematic SVG.
    [aqua_write_pcb.kicad_pcb, aqua_write_pcb.sch]
